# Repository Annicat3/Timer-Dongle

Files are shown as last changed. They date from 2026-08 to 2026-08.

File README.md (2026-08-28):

# Timer-Dongle
3D-Viewer (2)

## What is it?
This project is a small USB timer based on the CH552G microcontroller. It has 6 LEDs, a piezo buzzer and 2 buttons.  
The time can be selected in 10-minute steps, from 10 to 60 minutes. The LEDs show the selected time ans later show the progress of the timer. 
When the Timer finishes, the LEDs blink and the buzzer makes a sound.  

## Why did I make it?
I wanted to make something useful that I could actually use while working or studying. I also thought it would be fun to turn a simple electronic project into something with personality.  
Instead of using a normal rectangular PCB, I designed mine in the shape of a cat. I also added a small cat face and other details to the silkscreen.  

## How does it work?
1. Plug the timer into a USB port.
2. Press the time button to choose a time from 10 to 60 minutes.
3. Press the start button to start the timer.
4. The six LEDs slowly turn off as the timer runs.
5. When the timer reaches zero, the LEDs blink and the buzzer sounds.
6. Press the time button to stop the alarm and choose a new time.

## PCB  
I designed the schematic and PCB in KiCad.  

PCB  

### Schematic

Schematics  

### 3D View
3D-Viewer (2)

## Firmware
The Firmware is written for the CH552G using CH55xduino. 

## CAD
I also experimented with designing a simple case for the PCB in Onshape.  
[Onshape link](https://cad.onshape.com/documents/177762d436c217a9aff06dc5/w/83f6144ef2d4be5b708dd7f0/e/6c6f59c3ce17ec4403d9fee3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)  

CAD-assembly

## Bill of Materials (BOM)
|Item |  Qty | Cost | Link |
|---|---|---|---|
|PCB | 5 | $22.14 | [Gerber files](PCB/Timer-Dongle.gerbers.zip) |
| 3D printed case | 1 | $0.00 | [Stl File](CAD/Timer.Dongle.stl) |
|WCH CH552G Microcontroller | 1 | $0.75 | [LCSC C111292](https://www.lcsc.com/product-detail/Microcontrollers-MCU-MPU-SOC_WCH-Jiangsu-Qin-Heng-CH552G_C111292.html)|
| Murata GRM188R72A104KA35D, 100nF, 0603 | 2 | $0.18 | [LCSC C77058](https://www.lcsc.com/product-detail/C77058.html) |
| YAGEO RT0603BRD07470RL, 470Ω, 0603 | 6 | $0.55 | [LCSC C705779](https://www.lcsc.com/product-detail/C705779.html) |
| Panasonic ERA3AEB103V, 10kΩ, 0603 | 1 | $0.53 | [LCSC C190610](https://www.lcsc.com/product-detail/C190610.html) |
| XUNPU TS-1088-AC02016 tactile switch | 3 | $0.69 | [LCSC C720475](https://www.lcsc.com/product-detail/C720475.html) |
| Murata PKMCS0909E4000-R1 Piezo Buzzer | 1 | $1.02 | [LCSC C910763](https://lcsc.com/product-detail/Buzzers_Murata-Electronics-PKMCS0909E4000-R1_C910763.html) | 
| 0805 SMD LEDs | 6 | $2.43 | [LCSC C5879058](https://www.lcsc.com/product-detail/C5879058.html) |
| Shipping |  | $12,79 | |
| Total | | $41.08 | |

## Hack Club Dongle YSWS
This project was created as part of Hack Club's YSWS program, [Dongle](https://dongle.hackclub.com). It was my first time designing a PCB and I learned a lot about schematics, PCB design, routing, and choosing components along the way.

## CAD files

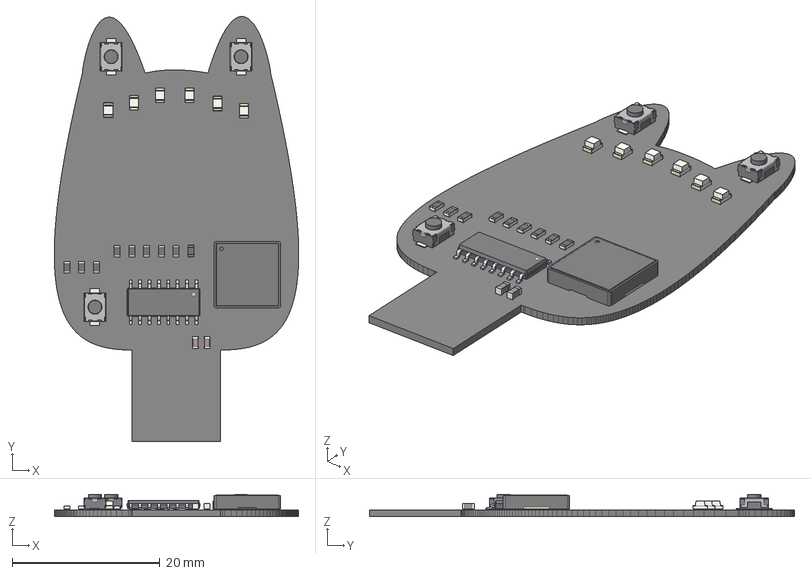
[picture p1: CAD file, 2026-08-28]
CAD/Timer.Dongle.step
33.1 x 57.6 x 3.00 mm
R_0603_1608Metric x 9
LED_0805_2012Metric x 6
SW_SPST_TS-1088-xR020 x 3
C_0603_1608Metric x 2
SOP-16_3.9x9.9mm_P1.27mm
Buzzer_Murata_PKMCS0909E4000_R1
Tim6B9D_PCB

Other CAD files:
CAD/Timer.Dongle.stl

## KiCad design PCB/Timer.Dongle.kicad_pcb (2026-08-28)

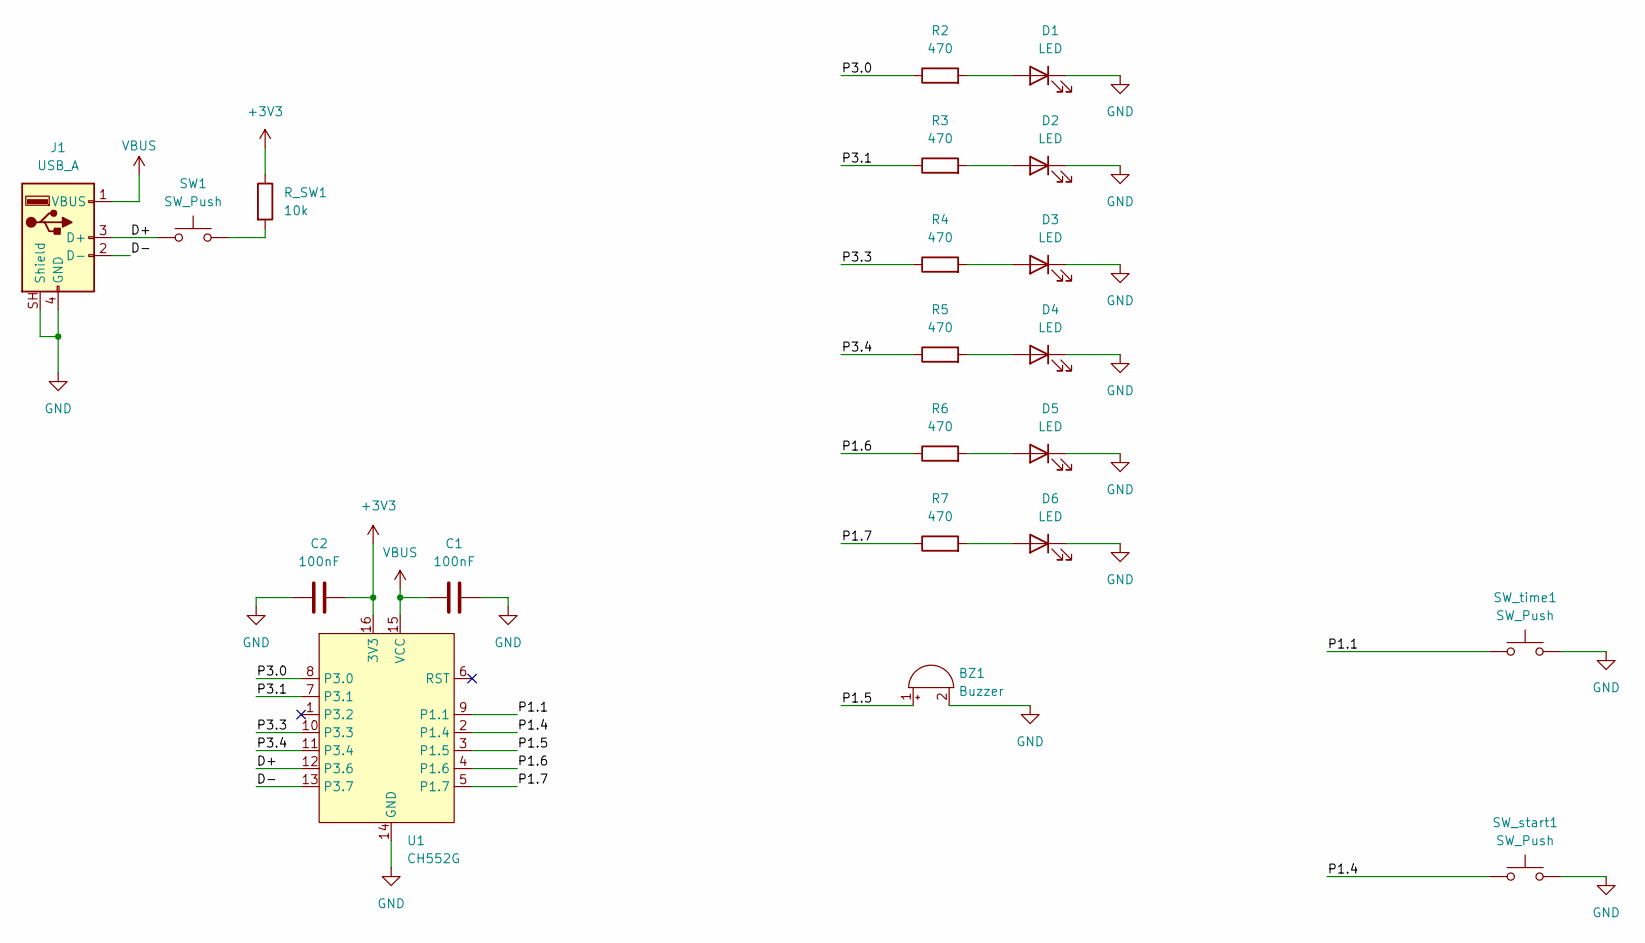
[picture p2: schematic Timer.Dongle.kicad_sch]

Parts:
BZ1: Buzzer; Buzzer_Murata_PKMCS0909E
C1, C2: 100nF; C_0603_1608Metric
D1, D2, D3, D4, D5, D6: LED; LED_0805_2012Metric
J1: USB_A; USB-A
R2, R3, R4, R5, R6, R7: 470; R_0603_1608Metric
R_SW1: 10k; R_0603_1608Metric
SW1: SW_Push; SW_SPST_TS-1088-xR020
SW_start1: SW_Push; SW_SPST_TS-1088-xR020
SW_time1: SW_Push; SW_SPST_TS-1088-xR020
U1: CH552G; JEITA_SOIC-16_3.9x9.9mm_P1.27mm

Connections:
+3V3: C2.1, R_SW1.1, U1.16 (3V3)
/D+: J1.3 (D+), SW1.1, U1.12 (P3.6)
/D-: J1.2 (D-), U1.13 (P3.7)
/P1.1: SW_time1.1, U1.9 (P1.1)
/P1.4: SW_start1.1, U1.2 (P1.4)
/P1.5: BZ1.1 (+), U1.3 (P1.5)
/P1.6: R6.1, U1.4 (P1.6)
/P1.7: R7.1, U1.5 (P1.7)
/P3.0: R2.1, U1.8 (P3.0)
/P3.1: R3.1, U1.7 (P3.1)
/P3.3: R4.1, U1.10 (P3.3)
/P3.4: R5.1, U1.11 (P3.4)
GND: BZ1.2 (-), C1.1, C2.2, D1.1 (K), D2.1 (K), D3.1 (K), D4.1 (K), D5.1 (K), D6.1 (K), J1.4 (GND), J1.SH (Shield), SW_start1.2, SW_time1.2, U1.14 (GND)
unnamed: D1.2 (A), R2.2
unnamed: D2.2 (A), R3.2
unnamed: D3.2 (A), R4.2
unnamed: D4.2 (A), R5.2
unnamed: D5.2 (A), R6.2
unnamed: D6.2 (A), R7.2
unnamed: R_SW1.2, SW1.2
VBUS: C1.2, J1.1 (VBUS), U1.15 (VCC)

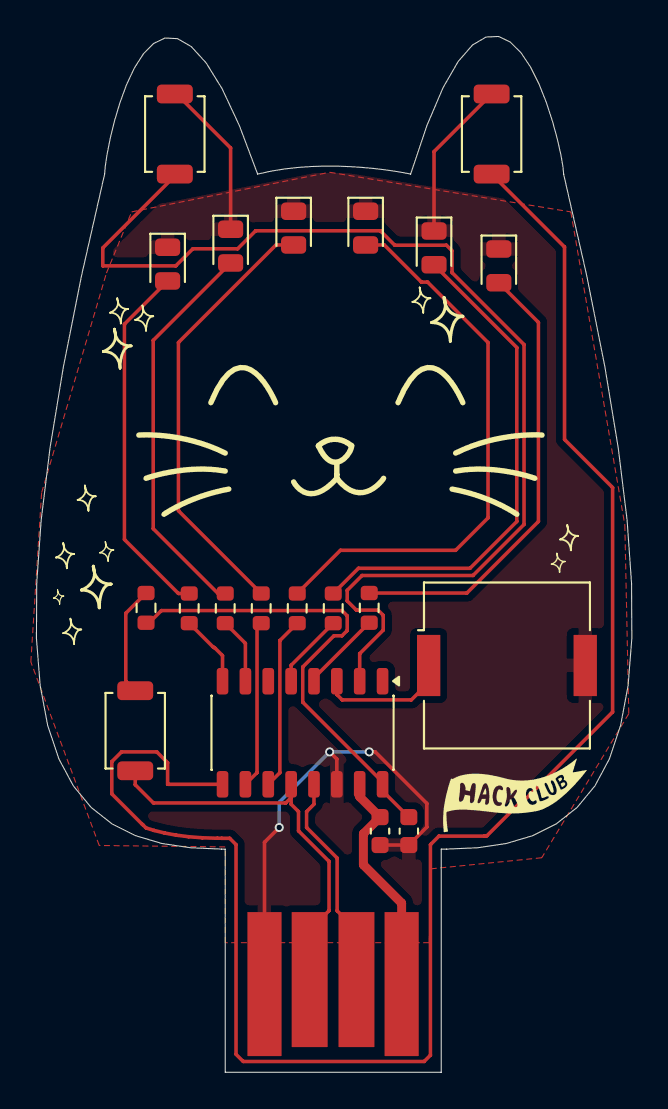
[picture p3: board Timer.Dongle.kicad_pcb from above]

Board: 2 copper layers, 33.1 x 57.5 mm, 21 parts (0 on the bottom side), 21 nets.

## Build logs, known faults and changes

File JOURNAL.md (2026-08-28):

## Timer-Dongle
A small USB timer dongle with 6 LEDs, a buzzer, and a cute cat-shaped PCB.  
*Total Hours: 13.5 hours*  

### August 26: Started the Timer-Dongle
*Time spent: 1.5 hours*  
Since I had never used KiCad or designed a PCB befor, I began by following the Dongle guide to learn the basics.
So far, I have started creating the schematic.
When I added the CH552G symbol library, I somehow deleted KiCad's built in symbol libraries. Suddenly, symbols like GND were missing, and the CH552G was basically the only thing that appeared when I seached for symbols. 
It took me a while to figure out what had happened, but I eventually restored the libraries and added the CH552G again.

Next, I want to add all the components I need for my own dongle to the schematic.
My current idea is to make a timer dongle with 6 LEDs and 2 buttons. One button will be used to select the timer lenght in 10-minute steps, from 10 to 60 minutes. 
The LEDs will show the selected time: for example, three LEDs could mean 30 minutes.When the timer is running, the LEDs will instead show roughly how much time is left.
The second button will start or pause the timer. I also want to add a piezo buzzer that makes a sound when the timer is finished. 
I think I have just enough free pins on the CH552G for all these components, but still need to plan exactly which pins to use.

### August 26: Finishing the schematic
*Time spent: 2 hours*  
I added the other components to the schematic. For the LEDs, I might have to check the resistor values again later, depending on which LEDs I end up choosing.
I also started looking for a piezo buzzer and found one that isn't too big. It's actually square, which surprised me because I had only seen round buzzers before!
I still have one free pin on the microcontroller in case I decided to add something else, like a small display. For now, though, I'm leaving it unused.  
After that I assigned the footprints. It took me a while to understand how the footprint assignment window works and where I was supposed to enter everything. i mostly used the footprints suggested in the guide, except for the buzzer. I might change some of the other components and footprints later once i choose the exact parts.  



Next, I'm going to start designing the actual PCB! I still have to decide on a shape for the board.

### August 27: PCB Design
*Time spent: 4 hours*  
I finally got to the exciting part: designing the actual PCB! I started by arranging all the components and experimenting with different shapes. 
After trying out a few ideas, I decided to make the PCB shaped like a cat! I think it looks really cute.



Routing everything was definitely challenging, especially around the microcontroller wher there are lots of connections close together. 
I also drawed a cute, simple cat face to the empty space on the pcb and added a tiny HackClub flag.

Next, I have to write the BOM (I really don't know how to do that) and design a 3D Case.

### August 27: BOM and Onshape
*Time spent: 2 hours*  
I worked on the Bill of Materials. This was a little more complicated than I excepted because I had to make sure that the parts actually matched my footprint, were available and could be ordered in the quantities I needed. I had to look at several different options for some components, especially the buttons and leds.

CAD-assembly

I also tried making a simple case for the PCB in Onshape. I had never really used Onshape before, so I had to experiment a bit. My original idea was to create a wall around the PCB and add a small overhang at the top to hold the PCB in place when the case was turned upside down. Unfortunately, I couldn't get the overhang to work the way I wanted.
It didn't turned out how I originally imagined it, but I still like it.

### August 28: Final steps and Submission
*Time spent: 4 hours*  
For the last part of my project, I worked on the firmware. I already knew the Arduino IDE from school, so this part wasn't too difficult for me.  
After that, I created the GitHub repository for the project. I uploaded all the files and wrote a README explaining what the Timer Dongle does and how it works. At first, I had uploaded all the files without really organizing them, so everything was a bit messy. I ended up deleting some duplicate files and organizing the remaining files into folders instead.  
The last thing I was unsure about was the PCB ordering process. I didn't know if i was supposed to order the PCB myself, if someone else would do it, or id JLCPCB was only used to check the price. Luckily someone in the Dongle channel explained everything to me and helpt me understand what I needed to do. 

3D-Viewer

Now everything is ready and i can finally submit my project! I'm really happy that I made it though all the different parts of the project even though some of them where confusing at first. I learned a lot along the way, especially about PCB design, choosing components, creating a BOM and putting everything together in a repository.

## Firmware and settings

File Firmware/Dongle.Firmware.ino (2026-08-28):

const int timeBtn = 14;
const int startBtn = 12;
const int buzzer = 15; 
const int LED_COUNT = 6;
const int leds[LED_COUNT] = {30, 31, 33, 34, 16, 17};
const unsigned long MINUTE = 60000UL;
int selectedMinutes = 10;
bool timerRunning = false;
bool alarmActive = false;

unsigned long startTime;
unsigned long duration;

bool lastTimeBtn = HIGH;
bool lastStartBtn = HIGH;


void setup() {
  for (int i = 0; i < LED_COUNT; i++) {
    pinMode(leds[i], OUTPUT);
  }

  pinMode(timeBtn, INPUT);
  pinMode(startBtn, INPUT);
  pinMode(buzzer, OUTPUT);
  showLEDs(selectedMinutes / 10);
}


void loop() {
  checkButtons();

  if (timerRunning) {
    updateTimer();
  }

  if (alarmActive) {
    updateAlarm();
  }
}


void checkButtons() {
  bool timeState = digitalRead(timeBtn);
  bool startState = digitalRead(startBtn);

  if (lastTimeBtn == HIGH && timeState == LOW) {
    delay(20);

    if (digitalRead(timeBtn) == LOW) {
      if (alarmActive) {
        stopAlarm();
      }
      else if (!timerRunning) {
        selectedMinutes += 10;

        if (selectedMinutes > 60) {
          selectedMinutes = 10;
        }

        showLEDs(selectedMinutes / 10);
      }
    }
  }

  if (lastStartBtn == HIGH && startState == LOW) {
    delay(20);

    if (digitalRead(startBtn) == LOW && !timerRunning && !alarmActive) {
      startTimer();
    }
  }
  lastTimeBtn = timeState;
  lastStartBtn = startState;
}


void startTimer() {
  timerRunning = true;
  duration = selectedMinutes * MINUTE;
  startTime = millis();
}


void updateTimer() {
  unsigned long elapsed = millis() - startTime;
  if (elapsed >= duration) {
    timerRunning = false;
    alarmActive = true;
    return;
  }

  unsigned long remaining = duration - elapsed;
  int ledsToShow = (remaining * 6 + duration - 1) / duration;
  showLEDs(ledsToShow);
}


void showLEDs(int amount) {
  for (int i = 0; i < LED_COUNT; i++) {
    digitalWrite(leds[i], i < amount ? HIGH : LOW);
  }
}


void updateAlarm() {
  bool blink = (millis() / 500) % 2;
  bool beep = (millis() / 250) % 2;

  for (int i = 0; i < LED_COUNT; i++) {
    digitalWrite(leds[i], blink);
  }
  digitalWrite(buzzer, beep);
}


void stopAlarm() {
  alarmActive = false;
  digitalWrite(buzzer, LOW);

  selectedMinutes = 10;
  showLEDs(selectedMinutes / 10);
}

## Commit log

2026-08-26 Add initial journal entry for Timer-Dongle project
    Documented the progress of the Timer-Dongle PCB project, including initial challenges and future plans.
2026-08-26 Update JOURNAL with schematic and PCB design progress
    Added details about schematic completion, component selection, and PCB design plans.
2026-08-27 Update JOURNAL.md with PCB design details
    Documented progress on PCB design, including challenges and decisions.
2026-08-27 add bom
    Updated the Bill of Materials section with additional components and corrected links.
2026-08-27 Add entry for August 27: BOM and Onshape work
    Document progress on BOM and Onshape case design.
2026-08-27 Enhance README with project overview and BOM
    Expanded project details, including functionality and design.
2026-08-28 Add Hack Club Dongle YSWS project section to README
    Added a section about the Hack Club Dongle YSWS project, including insights on PCB design and component selection.
2026-08-28 Update BOM total cost and fix typo in description
    Updated the total cost in the Bill of Materials and corrected a typo in the project description.
2026-08-28 Revise Timer-Dongle journal with final project updates
    Updated project details and added final steps for the Timer-Dongle, including BOM work and firmware development.
2026-08-28 Update BOM with quantities for PCB and case
2026-08-28 Revise BOM pricing
    corrected pricing in the BOM section. Fixed typos in project description.
2026-08-28 Update PCB cost in Bill of Materials
2026-08-28 Revise BOM with links and update total cost
    Updated Bill of Materials with links to Gerber files and STL file, and corrected total cost.
2026-08-28 Fix link formatting in Bill of Materials section
2026-08-28 Update README with new images and BOM details
    Updated images and BOM quantities in README.
2026-08-28 Fix link to PCB Gerber files in README
    Corrected the link to the Gerber files for the PCB.
